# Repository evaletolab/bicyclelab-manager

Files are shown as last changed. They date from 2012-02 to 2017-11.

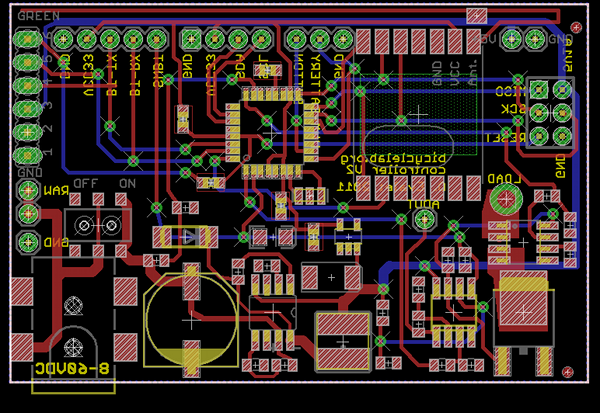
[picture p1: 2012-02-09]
hardware/bicyclelab-manager-v2.png

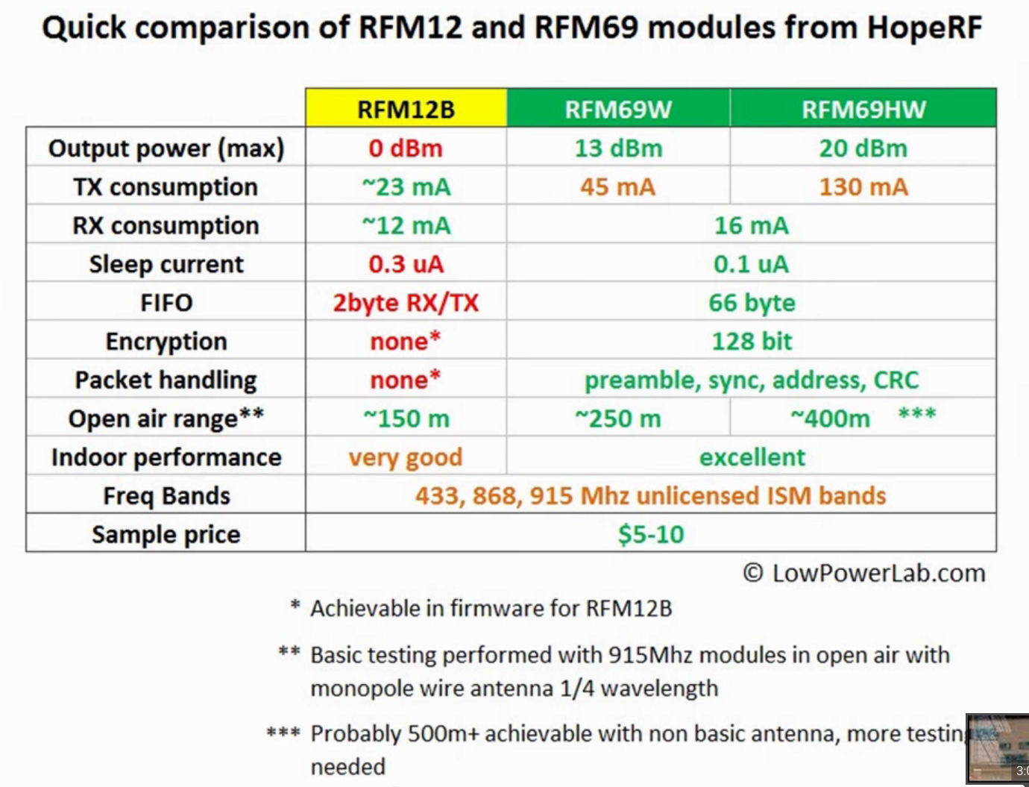
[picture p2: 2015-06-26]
docs/rfm12-vs-rfm69.png

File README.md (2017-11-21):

# Simple Wireless bicycle controller
This project depends on battery and charger from [evaletolab/bicyclelab-charger](../../../bicyclelab-charger)

All that stuff are plugged and tested here!
live testing

## Wireless switch (ON/OFF)
wireless switch
* the on/off switch is coupled with the integrated signal from the XYZ accelerometer.

## Features
1. Control electric bicycle plugged with the battery [evaletolab/bicyclelab-charger](../../../bicyclelab-charger),
2. 16kb flash,
3. Sensors for battery current and battery voltage,
3. 3 axis accelerometer available (automatic force detection to control motor power),
3. RFM12b for IO
4. controll external ESC with PWM or voltage
2. full protections: Short circuit / Overload / Over voltage 
7. small size, only ~23x48x4mm

The PCB board controller v0.0

**THIS IS ALPHA SOFTWARE/HARDWARE AND SHOULD BE TREATED ACCORDINGLY.**
**IT IS FUN TO GET RUNNING, BUT EXPECT THINGS TO BE BROKEN.**
 
## License
GPL3

Copyright (c) 2012 Olivier Evalet (http://evaletolab.ch/)

Permission is hereby granted, free of charge, to any person obtaining a copy
of this software and associated documentation files (the “Software”), to deal
in the Software without restriction, including without limitation the rights
to use, copy, modify, merge, publish, distribute, sublicense, and/or sell
copies of the Software, and to permit persons to whom the Software is
furnished to do so, subject to the following conditions:

The above copyright notice and this permission notice shall be included in
all copies or substantial portions of the Software.

THE SOFTWARE IS PROVIDED “AS IS”, WITHOUT WARRANTY OF ANY KIND, EXPRESS OR
IMPLIED, INCLUDING BUT NOT LIMITED TO THE WARRANTIES OF MERCHANTABILITY,
FITNESS FOR A PARTICULAR PURPOSE AND NONINFRINGEMENT. IN NO EVENT SHALL THE
AUTHORS OR COPYRIGHT HOLDERS BE LIABLE FOR ANY CLAIM, DAMAGES OR OTHER
LIABILITY, WHETHER IN AN ACTION OF CONTRACT, TORT OR OTHERWISE, ARISING FROM,
OUT OF OR IN CONNECTION WITH THE SOFTWARE OR THE USE OR OTHER DEALINGS IN
THE SOFTWARE.

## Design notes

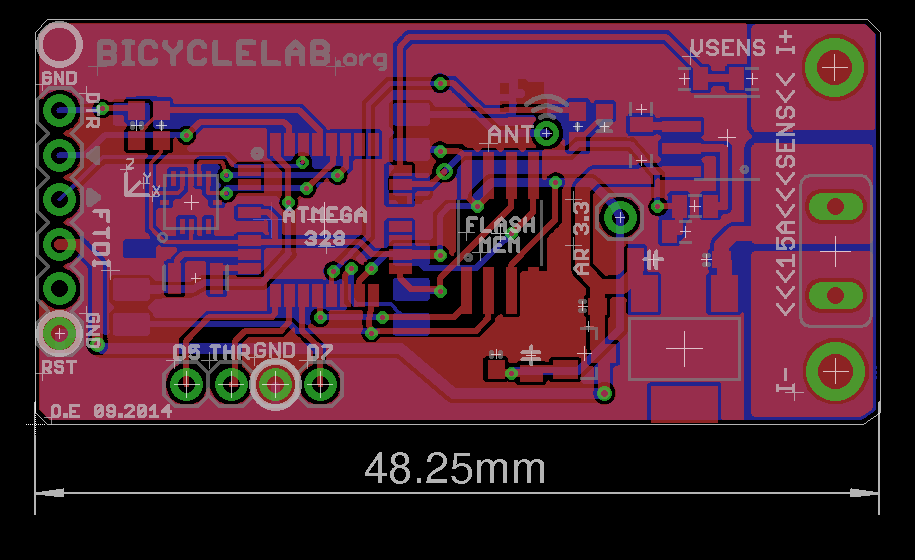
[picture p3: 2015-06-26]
docs/pcb.png

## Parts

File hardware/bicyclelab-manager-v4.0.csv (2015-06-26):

Qty | Value | Device | Package | Parts | Description | MF | MODEL1 | MODEL2 | MPN | OC_FARNELL | OC_NEWARK
1 |  | MMA7660FC-DFN10 | DFN10 | MMA7660FC | http://search.digikey.com/scripts/DkSearch/dksus.dll?Detail&name=MMA7660FCT-ND
2 | 0.1 | CAP0603-CAP | 0603-CAP | C1, C4 | Capacitor
1 | 0.1uF | CAP0805 | 0805 | C11 | Capacitor
1 | 10k | RESISTOR0603-RES | 0603-RES | R1 | Resistor
1 | 10k 0.1% | RESISTOR | 0805 | R9 | Resistor
2 | 10u | CAP0805-CAP | 0805-CAP | C3, C8 | Capacitor
1 | 16 MHz | RESONATORSMD | RESONATOR-SMD | X1 | Resonator
1 | 1M 0.1% | RESISTOR | 0805 | R10 | Resistor
1 | 1k5 | RESISTOR0603-RES | 0603-RES | R2 | Resistor
1 | 1nF | CAP0805 | 0805 | C6 | Capacitor
2 | 1u | CAP0603-CAP | 0603-CAP | C2, C7 | Capacitor
1 | 4.7k 0.1% | RESISTOR | 0805 | R8 | Resistor
1 | 82k 0.1% | RESISTOR | 0805 | R11 | Resistor
1 | ACS712 | ACS712 | SO08 | U$6
1 | AT25F512BWIDE_5.3MM | AT25F512BWIDE_5.3MM | SO08WIDE | W25X40CLSNIG-ND | 4-Mbit SPI flash memory
1 | ATMega-328 | ATMEGA168/328TQFP32 | TQFP32-08 | ATMEGA328 | Atmel 32-pin 8-bit micro, 16k flash.
1 | FTDI | M06SIP | 1X06 | FTDI | Header 6
1 | FUSETE5 | FUSETE5 | TE5 | F1 | Fuse |  |  |  |  | unknown | unknown
1 | LDO-5V-0.5A | LDO-5V-0.5A | SOT223 | IC1 | 500mA Low Dropout (LDO) Positive Regulator |  | uA78M00 | SPX2945M3
1 | LED0603 | LED0603 | 0603-LED | U$2
5 | M01PTH | M01PTH | 1X01 | +, JP1, OUT1, SEN, THROTTLE | Header 1
2 | M01PTH_2MM | M01PTH_2MM | 1X01_2MM | +1, +2 | Header 1
1 | MCP1703CB | MCP1703CB | SOT23 | IC3 | 250 mA, 16V, Low Quiescent Current LDO Regulator
1 | RFM12B_ANTENNA | RFM12B_ANTENNA | RFM12B-ANTENNA | U$1
1 | RFM12B_MINPADS | RFM12B_MINPADS | RFM12B-MINPADS | RFM12B

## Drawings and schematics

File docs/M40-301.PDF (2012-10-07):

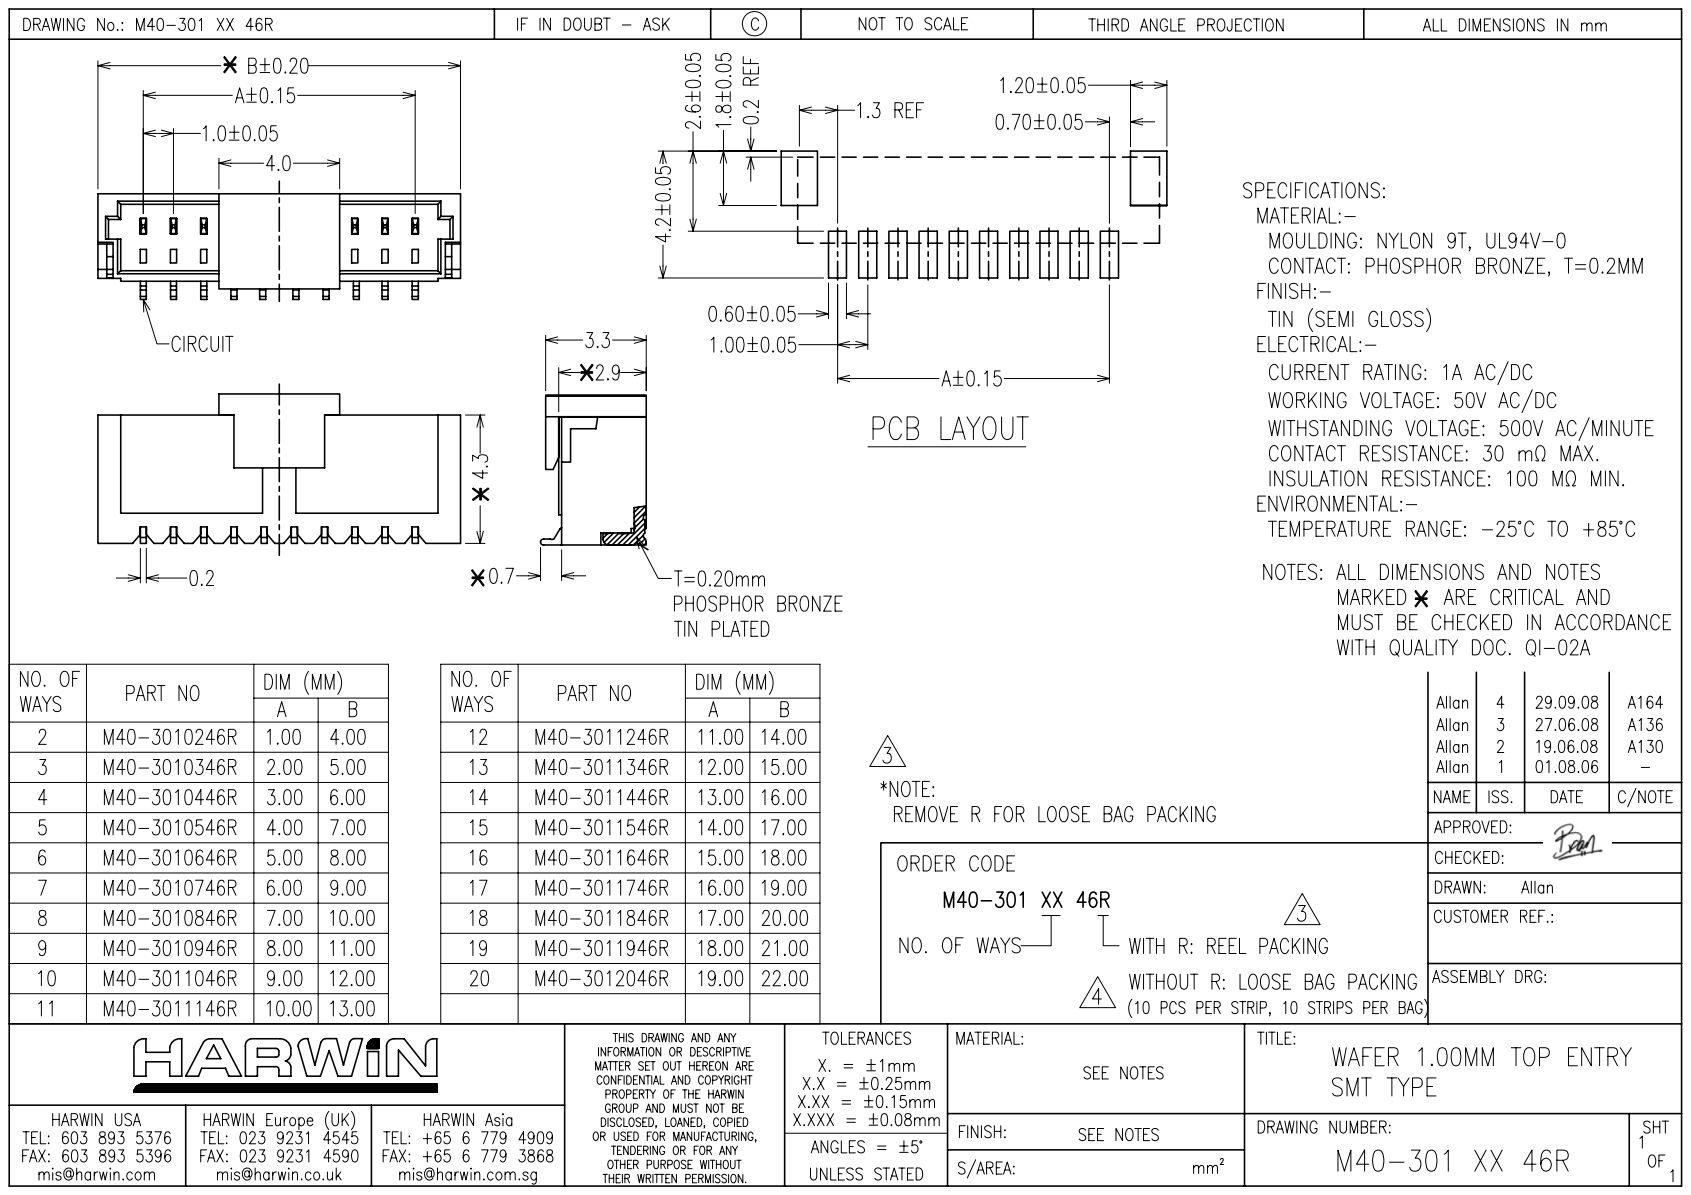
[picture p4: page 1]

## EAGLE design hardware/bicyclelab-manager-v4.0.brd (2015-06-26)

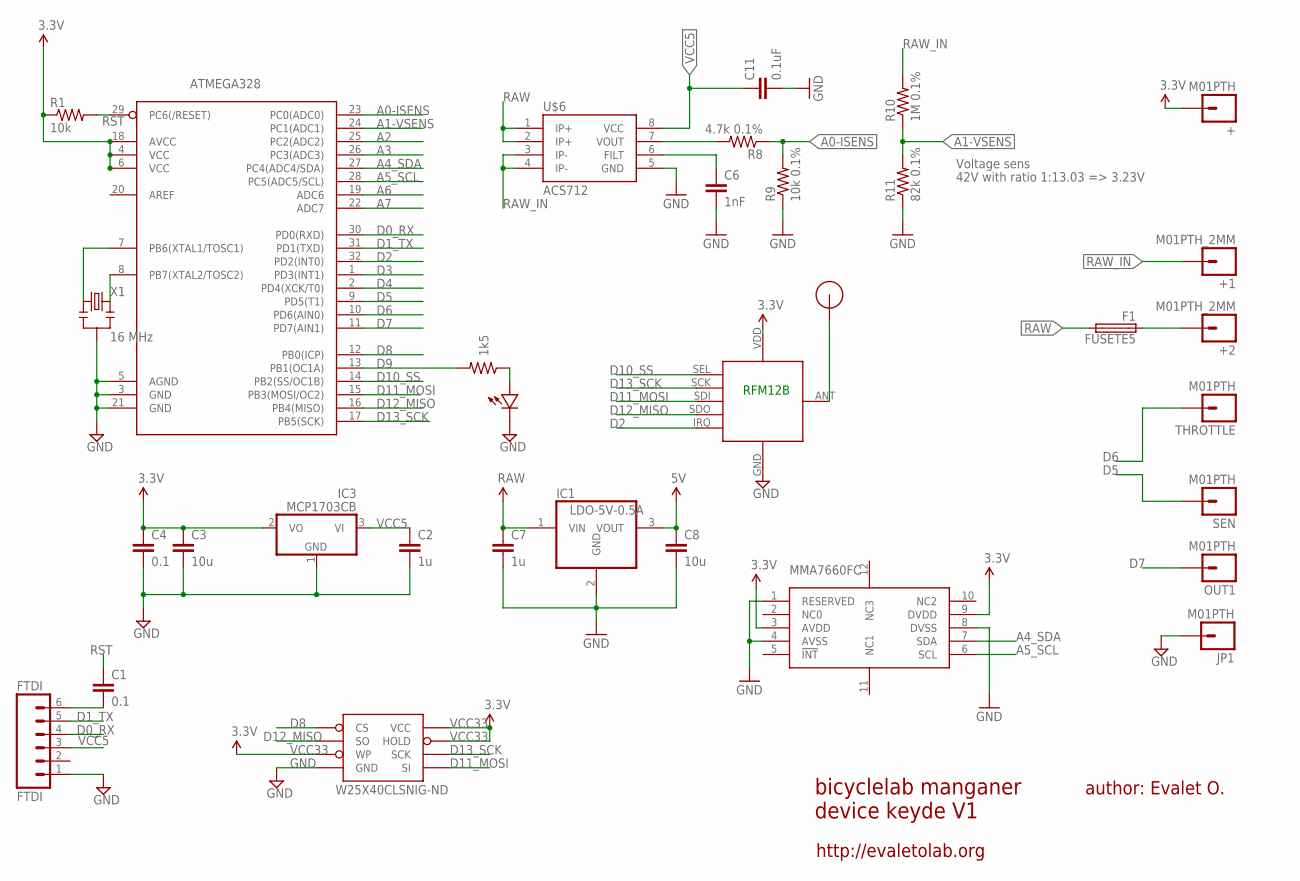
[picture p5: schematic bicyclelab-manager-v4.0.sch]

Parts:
+: M01PTH; 1X01
+1, +2: M01PTH_2MM; 1X01_2MM
ATMEGA328: ATMega-328; TQFP32-08
C1, C4: 0.1; 0603-CAP
C2, C7: 1u; 0603-CAP
C3, C8: 10u; 0805-CAP
C6: 1nF; 0805
C11: 0.1uF; 0805
F1: FUSETE5; TE5
FTDI: FTDI; 1X06
IC1: LDO-5V-0.5A; SOT223
IC3: MCP1703CB; SOT23
JP1: M01PTH; 1X01
MMA7660FC: MMA7660FC-DFN10; DFN10
OUT1: M01PTH; 1X01
R1: 10k; 0603-RES
R2: 1k5; 0603-RES
R8: 4.7k 0.1%; 0805
R9: 10k 0.1%; 0805
R10: 1M 0.1%; 0805
R11: 82k 0.1%; 0805
RFM12B: RFM12B_MINPADS; RFM12B-MINPADS
SEN: M01PTH; 1X01
THROTTLE: M01PTH; 1X01
U$1: RFM12B_ANTENNA; RFM12B-ANTENNA
U$2: LED0603; 0603-LED
U$6: ACS712; SO08
W25X40CLSNIG-ND: AT25F512BWIDE_5.3MM; SO08WIDE
X1: 16 MHz; RESONATOR-SMD

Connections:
A0-ISENS: ATMEGA328.23 (PC0(ADC0)), R8.1, R9.2
A1-VSENS: ATMEGA328.24 (PC1(ADC1)), R10.1, R11.2
A2: ATMEGA328.25 (PC2(ADC2))
A3: ATMEGA328.26 (PC3(ADC3))
A4_SDA: ATMEGA328.27 (PC4(ADC4/SDA)), MMA7660FC.7 (SDA)
A5_SCL: ATMEGA328.28 (PC5(ADC5/SCL)), MMA7660FC.6 (SCL)
A6: ATMEGA328.19 (ADC6)
A7: ATMEGA328.22 (ADC7)
D0_RX: ATMEGA328.30 (PD0(RXD)), FTDI.4
D1_TX: ATMEGA328.31 (PD1(TXD)), FTDI.5
D2: ATMEGA328.32 (PD2(INT0)), RFM12B.IRQ
D3: ATMEGA328.1 (PD3(INT1))
D4: ATMEGA328.2 (PD4(XCK/T0))
D5: ATMEGA328.9 (PD5(T1)), SEN.1
D6: ATMEGA328.10 (PD6(AIN0)), THROTTLE.1
D7: ATMEGA328.11 (PD7(AIN1)), OUT1.1
D8: ATMEGA328.12 (PB0(ICP)), W25X40CLSNIG-ND.1 (CS)
D9: ATMEGA328.13 (PB1(OC1A)), R2.2
D10_SS: ATMEGA328.14 (PB2(SS/OC1B)), RFM12B.SEL
D11_MOSI: ATMEGA328.15 (PB3(MOSI/OC2)), RFM12B.SDI (SDI/MOSI), W25X40CLSNIG-ND.5 (SI)
D12_MISO: ATMEGA328.16 (PB4(MISO)), RFM12B.SDO (SDO/MISO), W25X40CLSNIG-ND.2 (SO)
D13_SCK: ATMEGA328.17 (PB5(SCK)), RFM12B.SCK, W25X40CLSNIG-ND.6 (SCK)
GND: ATMEGA328.3 (GND), ATMEGA328.5 (AGND), ATMEGA328.21 (GND), C2.2, C3.2, C4.2, C6.2, C7.2, C8.2, C11.2, FTDI.1, IC1.2 (GND), IC3.1 (GND), JP1.1, MMA7660FC.1 (RESERVED), MMA7660FC.4 (AVSS), MMA7660FC.8 (DVSS), R9.1, R11.1, RFM12B.GND, U$2.MINUS, U$6.5 (GND), W25X40CLSNIG-ND.4 (GND), X1.2
IOUT_: R8.2, U$6.7 (VOUT)
unnamed: ATMEGA328.7 (PB6(XTAL1/TOSC1)), X1.1
unnamed: R2.1, U$2.PLUS
unnamed: RFM12B.ANT, U$1.P$1
unnamed: C6.1, U$6.6 (FILT)
unnamed: C1.2, FTDI.6
unnamed: ATMEGA328.8 (PB7(XTAL2/TOSC2)), X1.3
RAW: C7.1, F1.2, IC1.1 (VIN), U$6.1 (IP+), U$6.2 (IP+)
RAW_IN: +1.1, R10.2, U$6.3 (IP-), U$6.4 (IP-)
RAW_OUT: +2.1, F1.1
RST: ATMEGA328.29 (PC6(/RESET)), C1.1, R1.2
VCC5: C2.1, C8.1, C11.1, FTDI.3, IC1.3 (VOUT), IC3.3 (VI), U$6.8 (VCC)
VCC33: +.1, ATMEGA328.4 (VCC), ATMEGA328.6 (VCC), ATMEGA328.18 (AVCC), C3.1, C4.1, IC3.2 (VO), MMA7660FC.3 (AVDD), MMA7660FC.9 (DVDD), R1.1, RFM12B.VDD, W25X40CLSNIG-ND.3 (WP), W25X40CLSNIG-ND.7 (HOLD), W25X40CLSNIG-ND.8 (VCC)

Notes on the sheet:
bicyclelab manganer device keyde V1
author: Evalet O.
http://evaletolab.org
RFM12B
42V with ratio 1:13.03 => 3.23V
Voltage sens

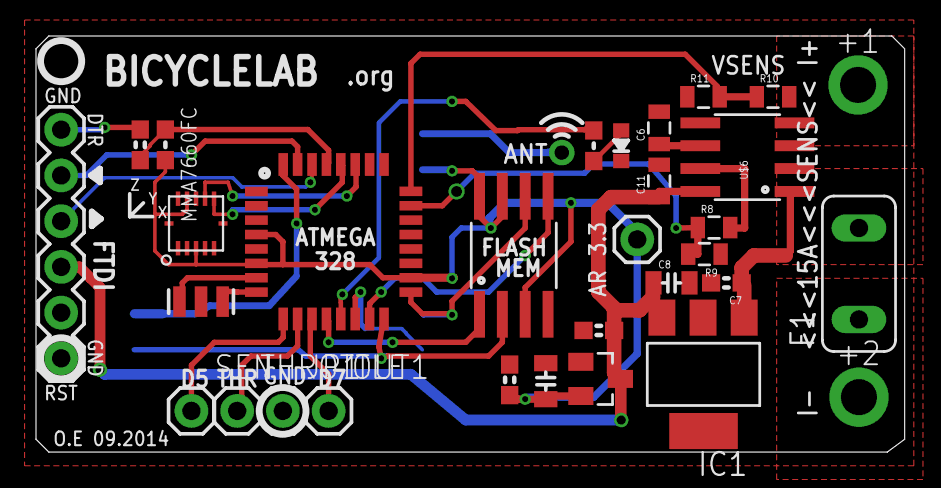
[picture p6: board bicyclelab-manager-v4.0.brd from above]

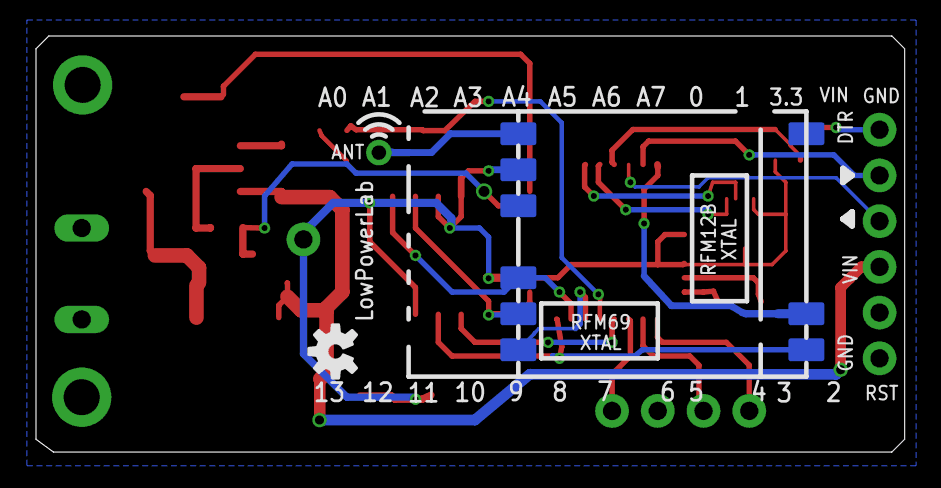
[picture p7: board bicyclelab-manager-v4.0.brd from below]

Board: 2 copper layers, 48.3 x 23.1 mm, 34 parts (2 on the bottom side), 30 nets.

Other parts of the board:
U$3: OSHW-LOGO-S

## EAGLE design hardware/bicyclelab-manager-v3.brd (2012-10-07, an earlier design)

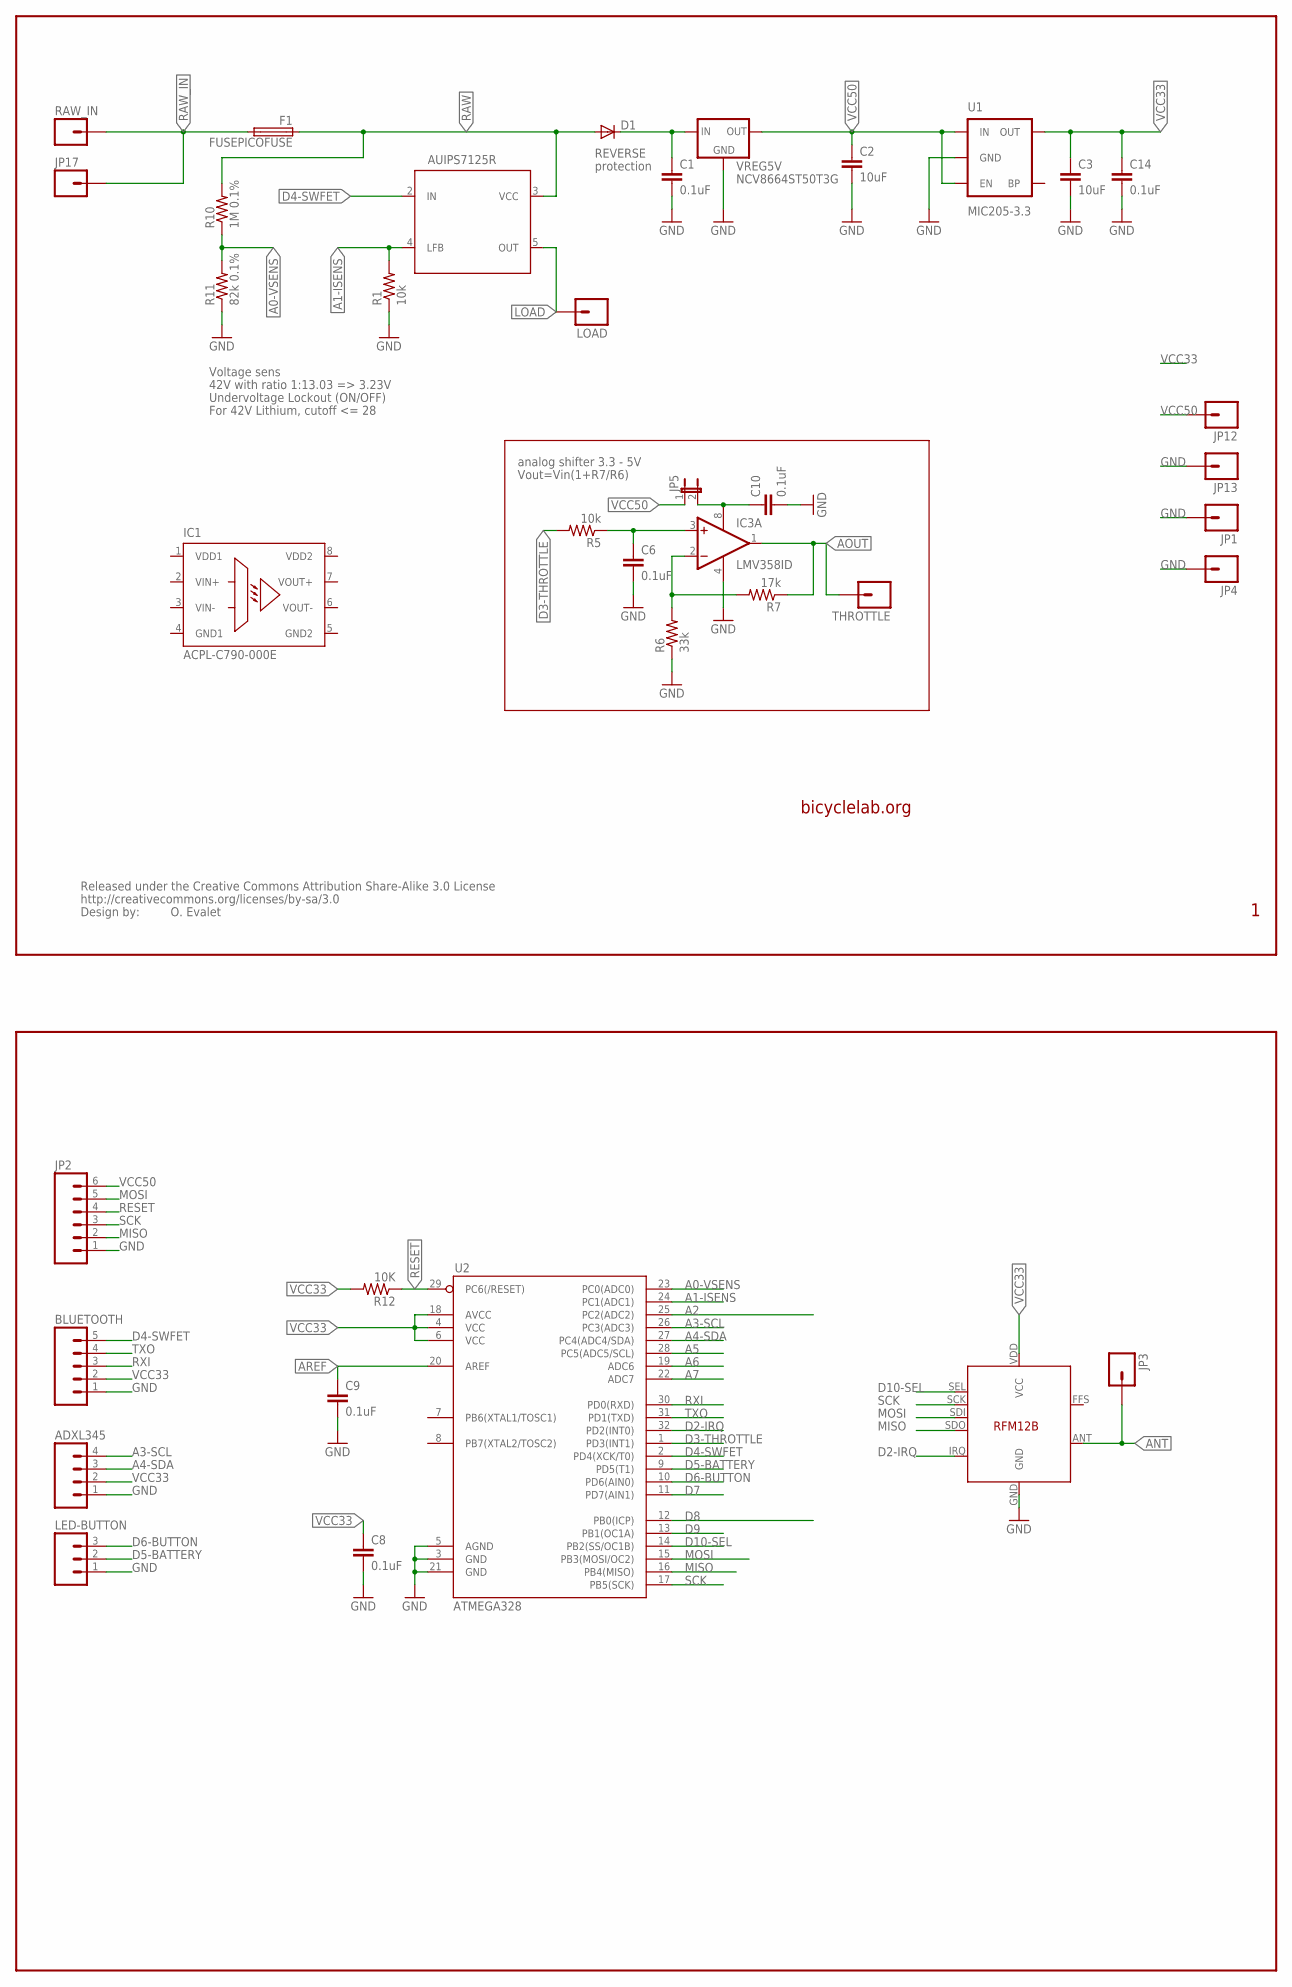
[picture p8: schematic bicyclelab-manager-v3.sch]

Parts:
ADXL345: M04PTH; 1X04
BLUETOOTH: M05PTH; 1X05
C1, C6, C10: 0.1uF; 0805
C2, C3: 10uF; 0805
C8, C9, C14: 0.1uF; 0603-CAP
D1: DIODESOD; SOD-323
F1: FUSEPICOFUSE; PICOFUSE
IC1: ACPL-C790-000E; DIP8
IC3: LMV358ID; SO08
JP1, JP4, JP17: M01PTH_2MM; 1X01_2MM
JP2: M06EM406; EM406
JP3: M01SMD-4.5X1.5; PAD-1.5X4.5
JP5: JUMPER-2PTH_LOCK; 1X02_LOCK
JP12, JP13: M01PTH; 1X01
LED-BUTTON: M03PTH; 1X03
LOAD: M01PTH_2MM; 1X01_2MM
R1, R5: 10k; 0805
R6: 33k; 0805
R7: 17k; 0805
R10: 1M 0.1%; 0805
R11: 82k 0.1%; 0805
R12: 10K; 0603-RES
RAW_IN: M01PTH_2MM; 1X01_2MM
THROTTLE: M01PTH; 1X01
U1: MIC205-3.3; SOT23-5
U2: ATMEGA328; TQFP32-08
U$1: RFM12B
U$5: CREATIVE_COMMONS
U$8: AUIPS7125R; DPAK-5
VREG5V: NCV8664ST50T3G; SOT223

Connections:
A0-VSENS: R10.1, R11.2, U2.23 (PC0(ADC0))
A1-ISENS: R1.2, U2.24 (PC1(ADC1)), U$8.4 (LFB)
A2: U2.25 (PC2(ADC2))
A3-SCL: ADXL345.4, U2.26 (PC3(ADC3))
A4-SDA: ADXL345.3, U2.27 (PC4(ADC4/SDA))
A5: U2.28 (PC5(ADC5/SCL))
A6: U2.19 (ADC6)
A7: U2.22 (ADC7)
ANT: JP3.P$1, U$1.ANT
AOUT: IC3.1 (OUT), R7.1, THROTTLE.1
AREF: C9.1, U2.20 (AREF)
D2-IRQ: U2.32 (PD2(INT0)), U$1.IRQ
D3-THROTTLE: R5.2, U2.1 (PD3(INT1))
D4-SWFET: BLUETOOTH.5, U2.2 (PD4(XCK/T0)), U$8.2 (IN)
D5-BATTERY: LED-BUTTON.2, U2.9 (PD5(T1))
D6-BUTTON: LED-BUTTON.3, U2.10 (PD6(AIN0))
D7: U2.11 (PD7(AIN1))
D8: U2.12 (PB0(ICP))
D9: U2.13 (PB1(OC1A))
D10-SEL: U2.14 (PB2(SS/OC1B)), U$1.SEL
GND: ADXL345.1, BLUETOOTH.1, C1.2, C2.2, C3.2, C6.2, C8.2, C9.2, C10.2, C14.2, IC3.4 (V-), JP1.1, JP2.1, JP4.1, JP13.1, LED-BUTTON.1, R1.1, R6.1, R11.1, U1.2 (GND), U2.3 (GND), U2.5 (AGND), U2.21 (GND), U$1.GND, VREG5V.2 (GND)
GND1: IC1.4 (GND1)
GND2: IC1.5 (GND2)
LOAD: LOAD.1, U$8.5 (OUT)
MISO: JP2.2, U2.16 (PB4(MISO)), U$1.SDO
MOSI: JP2.5, U2.15 (PB3(MOSI/OC2)), U$1.SDI
unnamed: C1.1, D1.1 (C), VREG5V.1 (IN)
unnamed: IC3.2 (-IN), R6.2, R7.2
unnamed: C6.1, IC3.3 (+IN), R5.1
RAW: D1.2 (A), F1.1, R10.2, U$8.3 (VCC)
RAW_IN: F1.2, JP17.1, RAW_IN.1
RESET: JP2.4, R12.1, U2.29 (PC6(/RESET))
RXI: BLUETOOTH.3, U2.30 (PD0(RXD))
SCK: JP2.3, U2.17 (PB5(SCK)), U$1.SCK
TXO: BLUETOOTH.4, U2.31 (PD1(TXD))
VCC33: ADXL345.2, BLUETOOTH.2, C3.1, C8.1, C14.1, R12.2, U1.5 (OUT), U2.4 (VCC), U2.6 (VCC), U2.18 (AVCC), U$1.VDD (VCC)
VCC50: C2.1, JP2.6, JP5.1, JP12.1, U1.1 (IN), U1.3 (EN), VREG5V.3 (OUT)
VCC50_: C10.1, IC3.8 (V+), JP5.2
VDD1: IC1.1 (VDD1)
VDD2: IC1.8 (VDD2)
VIN+: IC1.2 (VIN+)
VIN-: IC1.3 (VIN-)
VOUT+: IC1.7 (VOUT+)
VOUT-: IC1.6 (VOUT-)

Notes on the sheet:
bicyclelab.org
O. Evalet
Undervoltage Lockout (ON/OFF)
For 42V Lithium, cutoff <= 28
42V with ratio 1:13.03 => 3.23V
Voltage sens
analog shifter 3.3 - 5V
Vout=Vin(1+R7/R6)
REVERSE
protection

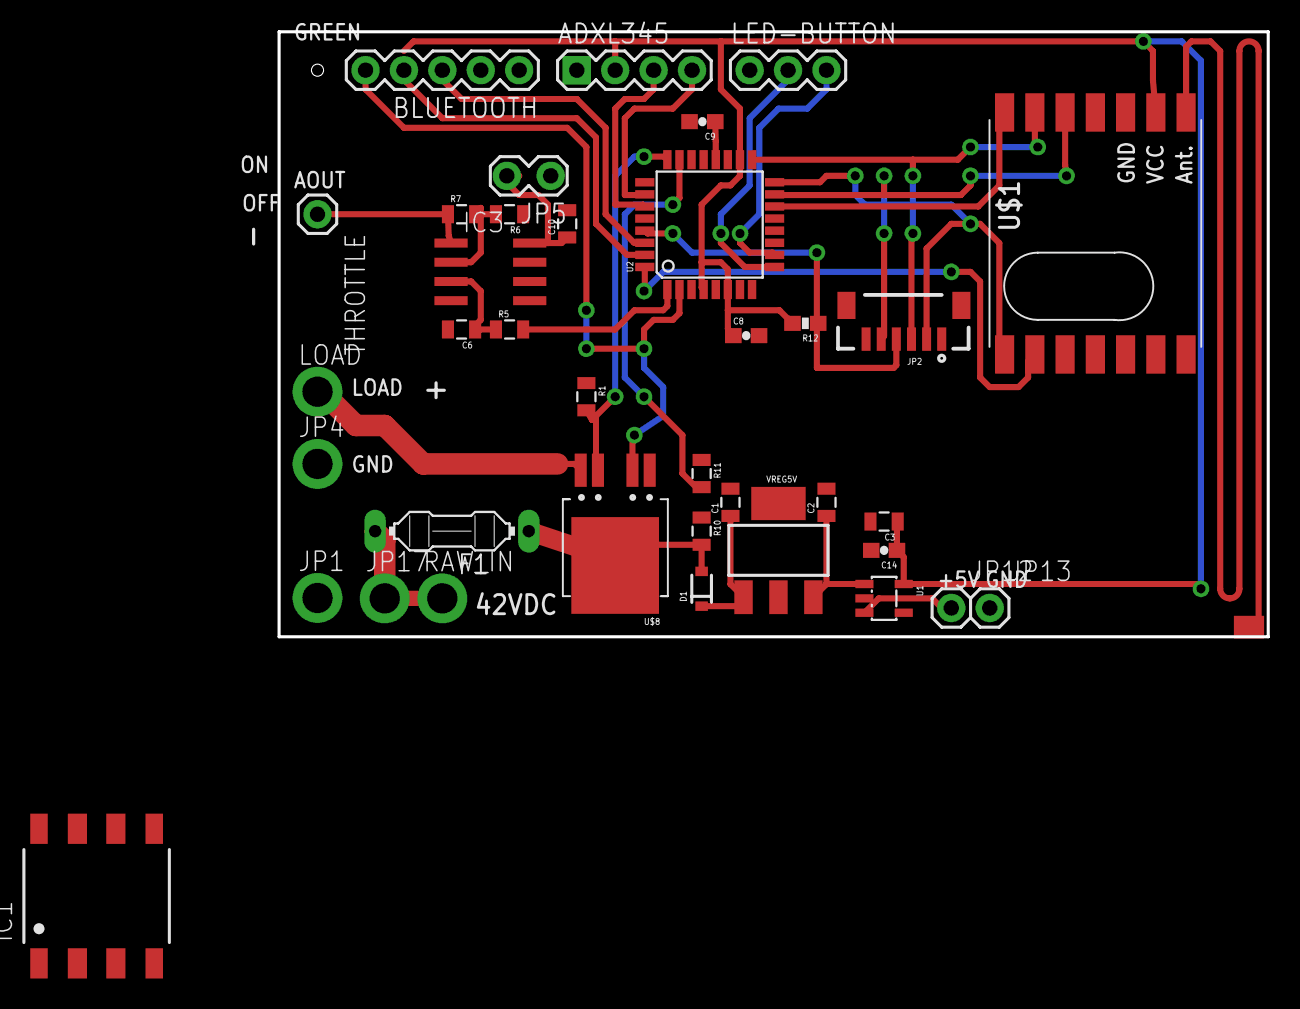
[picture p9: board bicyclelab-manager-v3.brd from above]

Board: 2 copper layers, 65.4 x 40.0 mm, 39 parts (0 on the bottom side), 29 nets.

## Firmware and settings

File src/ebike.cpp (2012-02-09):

/**
 * read value from accelerometer 
 *  roadmap:
 *  - get gravitation and init axes
 *  - make plan with orthogonal zvector
 *  - detect forward and backward
 * 
 *  # read post about pedale detection
 *  http://www.arduino.cc/cgi-bin/yabb2/YaBB.pl?num=1252694516/30
 *  
 */


#include "config.h"
#include <WProgram.h>
#include "ebike-tools.h" 
#include "ebike-sens.h" 
#include "ebike-accel.h" 
#include "ebike-controller.h"
#include "ebike-bluetooth.h"
#include "ebike-sleep.h"
#include <NewSoftSerial.h>


#ifdef CONFIG_WITH_EEPROM
#include <EEPROM.h>
#endif



#ifdef CONFIG_WITH_ECLIPSE
extern "C" void __cxa_pure_virtual() {  }
#endif


static int		sleep_time=SLEEP_CYCLE_DOWN;
static long 	dt=0, lasttime=0;
static float i,v;

static Accel accel;
static float vref;



void onsleep(void* data){
	bluetooth_disconnect();
	digitalWrite(P_SWFET,LOW);
	sleep_time=SLEEP_CYCLE_DOWN;
	//Serial.println("DOWN");
}
void onwakeup(void* data){
	digitalWrite(P_SWFET,HIGH);
	sleep_time=SLEEP_CYCLE_UP;
	//Serial.println("WAKEUP");
}


void setup()   {                
  // initialize the digital pin as VCC
  pinMode(P_VCC, OUTPUT);     
  pinMode(P_GND, OUTPUT);     
  pinMode(P_SWFET, OUTPUT);     
  pinMode(P_THROTTLE, OUTPUT);     
  digitalWrite(P_SWFET, LOW);
  digitalWrite(P_VCC, HIGH);
  digitalWrite(P_GND, LOW);

  Serial.begin(115200);
  
  //
  // init power manager
  //sleep_init();
  //sleep_watchdog(8);
  
  // init accel
  accel_init();

  // i_max, i_tilte, v_min, throttle
  controller_pwm_init(I_MAX,I_TILT, V_MIN, P_THROTTLE);
	sleep_init	(onsleep,onwakeup, NULL);  
}


void loop(){		   

  //
  // stay in sleep mode? 
  //   if (!power AND SLEEP_CYCLE_DOWN) then powerdown arduino
  //
	delay(10); //in case of wakeup time
  int power=digitalRead(P_POWER);
  //Serial.print(power);Serial.print(" ,");
	if (sleep_time==SLEEP_CYCLE_DOWN){
		dt=sleep_time+10;
		// During this time power consumption is minimised
		if (!power){
			sleep_delay(sleep_time);
			return;
		}
	}else{
		dt=sleep_time;
	}
	//
	// read sensors (internal voltage, batt current, batt voltage)      
	sens_init(vref);
	vref=sens_internal_vcc()/1000.0;
	i=sens_battery_current(A_I);
	v=sens_battery_voltage(A_V);
  
  
  //
  // get accel data structure
  //   pedelec_a, first direction of the X force 
  //   pedelec_b, second direction of the X force 
  //   filtered_forward_force, Low path filter on F[N]=m*a
	accel_update(accel,vref,1.0);
	
  if (power){
    power=controller_pwm_on(accel,i,v,dt);    
  }  
  
  //cut power when button is up
  if (power==0){
    controller_pwm_off();
  }
  
  sleep_update(accel,power,i,dt);
	
		
	bluetooth_send_pedelec(i,v,accel.pedelec_a,accel.pedelec_b,accel.filtered_forward_force);
  
	delay(100);
}

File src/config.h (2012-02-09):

/**
 * battery life calculator
 * http://oregonembedded.com/batterycalc.htm
 */

#ifndef CONFIG_H_
#define CONFIG_H_

#define CONFIG_WITH_DEBUG
#define CONFIG_WITH_ACCEL_I2C
#define CONFIG_WITH_ECLIPSE
//#define CONFIG_WITH_LOGGER
#define CONFIG_WITH_NARCOLEPTIC
#define CONFIG_WITH_BLUETOOTH
//#define CONFIG_WITH_TIMER

//
// battery managment
#define I_MAX 11
#define I_TILT 14
#define V_MIN 28
#define SLEEP_CYCLE_UP 200
#define SLEEP_CYCLE_DOWN 800
#define SLEEP_AFTER_TIME 180000
#define SLEEP_WHEN_I_LOWER 0.03
#define SENS_VOLTAGE_RATIO 13.03

// ACS712 20A = 100 +-4 mv/A @5VCC => 0.066 @3.3VCC
#define SENS_CURRENT_RATIO 15.1515
// middle value is less than 5VCC, 4.85/2=2.425*0.66=1.605 => 497bits
#define SENS_CURRENT_0 497

// the refresh time is set to limit the bt I/O and preserve the battery 
#define BLUETOOTH_REFRESH 1000

// the average must be proportianal to the refresh time
#define BLUETOOTH_HPF 0.3
#define BLUETOOTH_LPF 0.7

#define X 0
#define Y 1
#define Z 2

//
//ARDUINO I/O

//mosfet switch
#define P_SWFET 4

//battery led status PWM pulse
#define P_BATT_STATUS  5

#define A_V 0
#define A_I 1
#define P_THROTTLE 3

//RFM12B
#define RFM_IRQ  2
#define RFM_SEL  10
#define RFM_MOSI 11
#define RFM_MISO 12
#define RFM_SCK  13

//button
#define P_POWER 6

// power
#define P_GND  7
#define P_VCC  8



//bluetooth (STD SERIAL)
//#define P_BT_RX  5
//#define P_BT_TX  6

//datalogger 
#define P_DL_RX  3
#define P_DL_TX  4


#define HPF 0.98
#define LPF (1-HPF)

#endif

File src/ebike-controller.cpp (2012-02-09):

/*
 * output controller functions
 *
 */
#include "config.h"
#include "ebike-controller.h"
#include "ebike-tools.h"
#include <WProgram.h>
#include <math.h>



 /**
  * MANAGE PWM WITH CURRENT FEEDBACK
  * - maxpwm, calibration of the controller PWM
  * - lastcurrent, I-1
  * - current, I
  * - dt, sample time
  * - limit, current limit
  * - responcetime, amount of time to get effective the new PWM value. 
  *
  * Get inspired by the PID Controller (http://en.wikipedia.org/wiki/PID_controller) 
  * PID= Kp*Error + Ki*∫error*dt + Kd*(error-error1)/dt  
  *
  * 
  */
static int P_CONTROLLER;
  
void 	controller_pwm_init(int imax,int itilt, int vmin, int pout){
	P_CONTROLLER=pout;
	
	// Set pinout PWM frequency to 3906 Hz (31250/8 = 3906)
	// Note that the base frequency for pins 3, 9, 10, and 11 is 31250 Hz
	setPwmFrequency(P_CONTROLLER, 8);
}

int 	controller_pwm_on(Accel &accel, float I,float V, int dt){
  //no pedelec throttle is about 3.5V => 70% of 255 = 179
  #if 0
  if (no pedelec){
		analogWrite(P_CONTROLLER,179);
		return 0;
  }
  #endif
  //full throttle is 4.1V, 82% of 5V => 82% of 255 = 209
	analogWrite(P_CONTROLLER,209);
	return 1;
}

void 	controller_pwm_off(){
	analogWrite(P_CONTROLLER,0);
}

void 	controller_pwm_calibrate(){
}

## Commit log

2012-10-07 new release
    [bicyclelab-manager-v3.1.brd, bicyclelab-manager-v3.1.sch, bicyclelab-manager-v3.brd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]
2015-06-26 new release based on monteino hardware
    [bicyclelab-manager-keyde-v4.0.brd, bicyclelab-manager-keyde-v4.0.sch, bicyclelab-manager-v4.0.brd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]
2015-06-26 new pcb picture

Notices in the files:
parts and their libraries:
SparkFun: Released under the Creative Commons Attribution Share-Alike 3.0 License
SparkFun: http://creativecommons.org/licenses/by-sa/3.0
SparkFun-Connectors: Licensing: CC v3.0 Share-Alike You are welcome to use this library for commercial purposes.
